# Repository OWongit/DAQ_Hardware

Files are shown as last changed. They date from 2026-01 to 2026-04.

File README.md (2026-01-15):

# High-Precision Raspberry Pi DAQ Board

A custom Data Acquisition (DAQ) hat designed for the Raspberry Pi. This board interfaces with industrial sensors (RTDs, Load Cells, Pressure Transducers) to log and display live data with high precision.

The system features a robust, low-noise power architecture that manages 24VDC input to power the sensors, the precision analog circuitry, and the Raspberry Pi itself. It utilizes dual 24-bit ADCs communicating over SPI for high-resolution signal digitization.

## Features

* **Multi-Sensor Interface:** Three 15-position D-sub connectors for attaching RTDs, Load Cells, and Pressure Transducers.
* **Input Protection:** Every signal line is protected by TVS diode arrays to guard against ESD and surge events.
* **High-Resolution Sampling:** Dual 24-bit ADCs transmit data via SPI to the Raspberry Pi.
* **Low-Noise Power Architecture:**
    * Accepts 24 VDC input.
    * On-board Buck converters for high-efficiency voltage step-down.
    * LDOs and precision voltage references ensure clean power rails for the ADCs and sensors.
    * High-current supply dedicated to the Raspberry Pi.
* **Compact Design:** PCB fits within a 10cm x 10cm footprint to minimize manufacturing costs.

### 3D Rendering
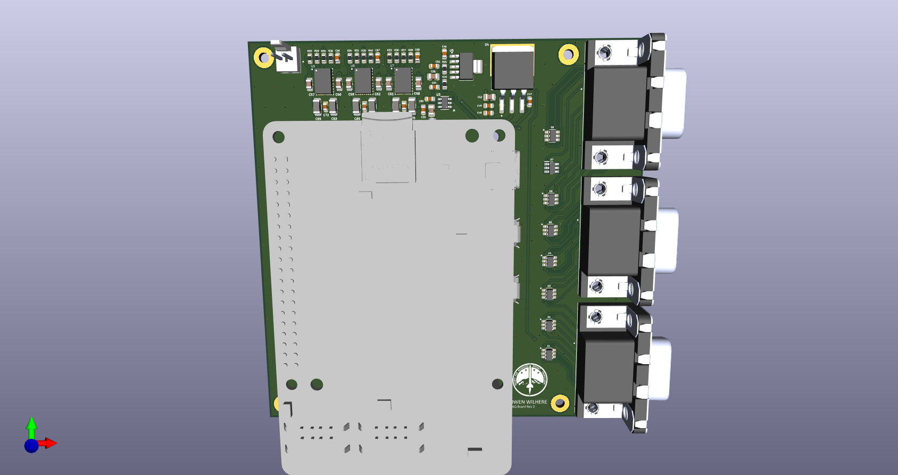
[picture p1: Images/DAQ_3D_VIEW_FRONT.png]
Business Card Front


### Layout View
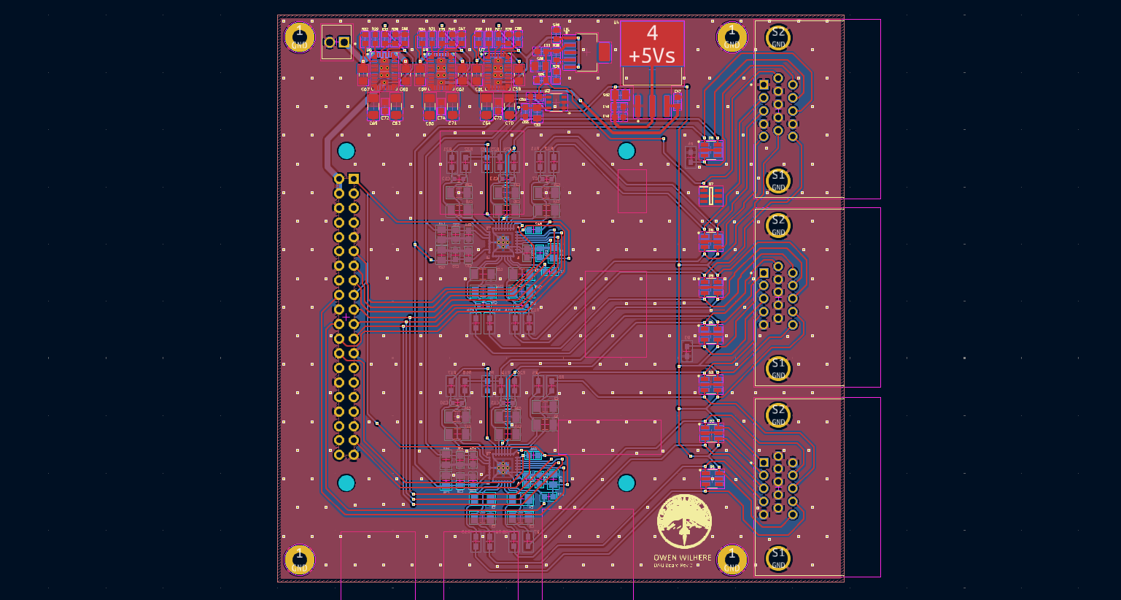
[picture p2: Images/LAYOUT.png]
PCB Layout


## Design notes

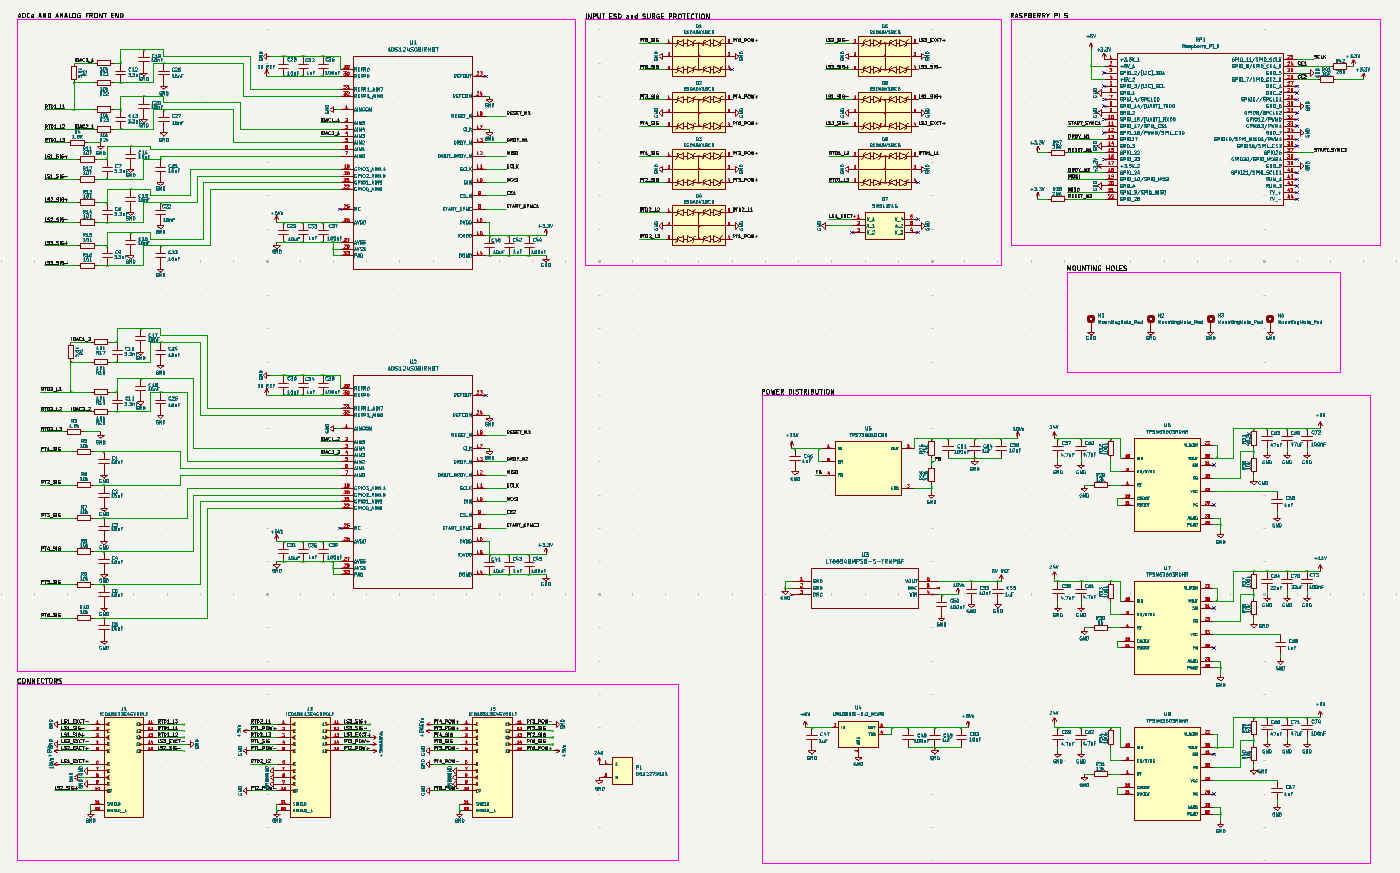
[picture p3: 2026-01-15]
Images/SCHEMATIC.png

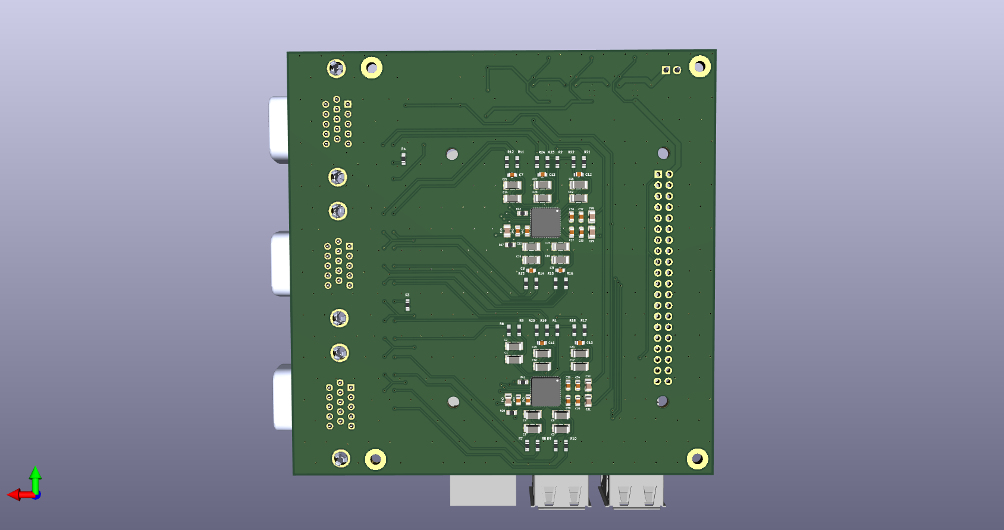
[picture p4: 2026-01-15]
Images/DAQ_3D_VIEW_BACK.png

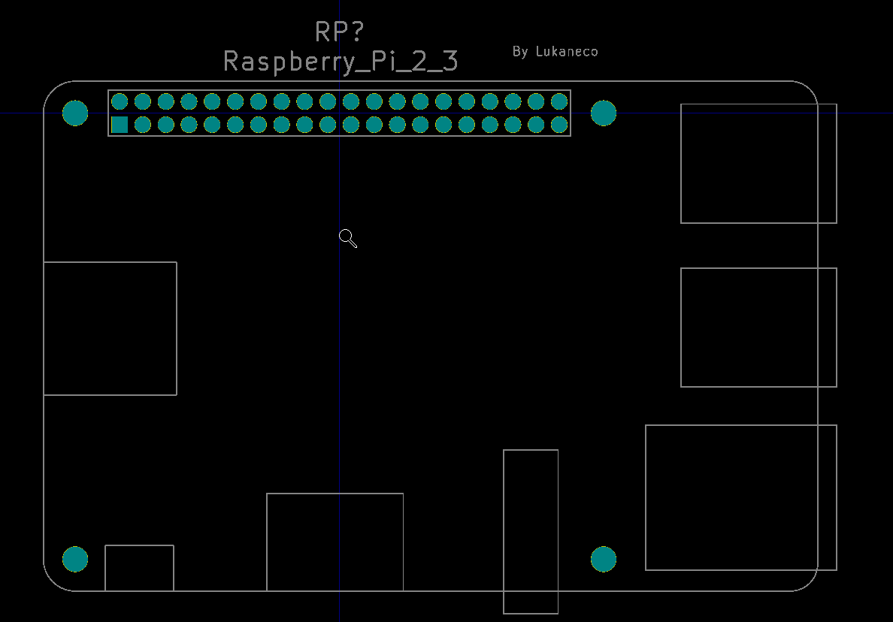
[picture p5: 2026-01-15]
DAQ symbols and footprints/raspberry pi 5/imagen.png

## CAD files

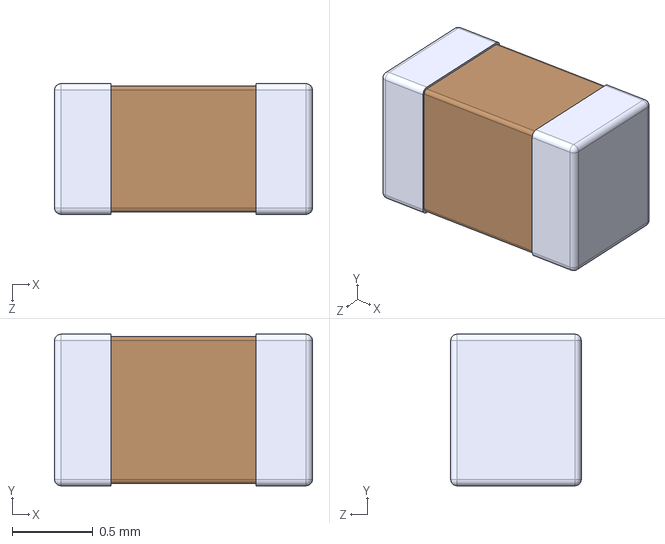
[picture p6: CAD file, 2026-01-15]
DAQ symbols and footprints/0603YC105JAT2A/CAPC1608X94N.step
1.60 x 0.94 x 0.81 mm

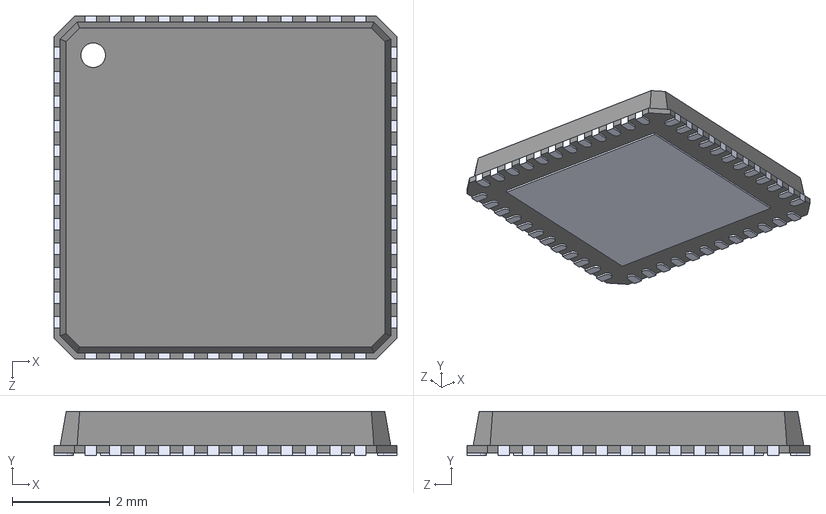
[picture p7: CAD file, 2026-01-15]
DAQ symbols and footprints/ADS1258IRTCT/ADS1258IRTCT.step
7.00 x 0.9 x 7.00 mm

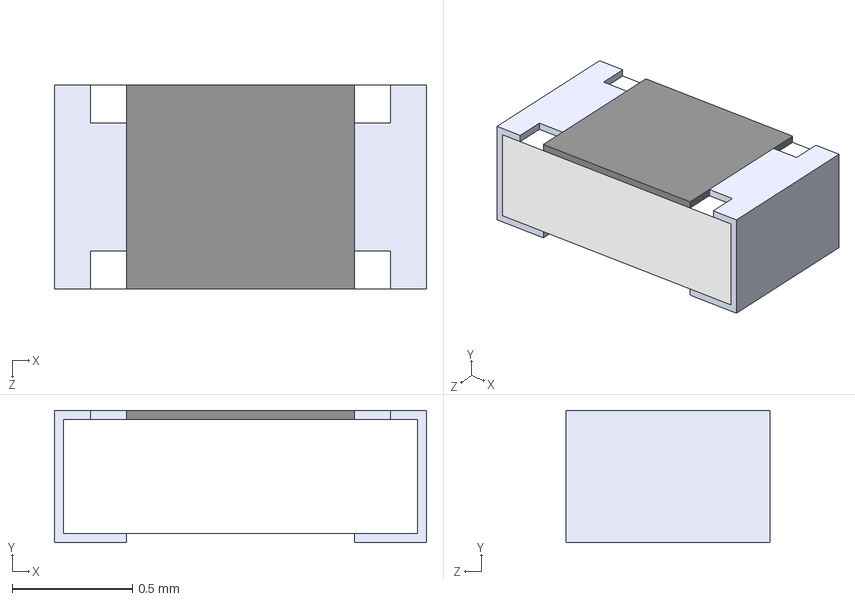
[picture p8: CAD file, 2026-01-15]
DAQ symbols and footprints/CRCW0603100KFKEA/CRCW0603100KFKEA.step
1.55 x 0.55 x 0.85 mm

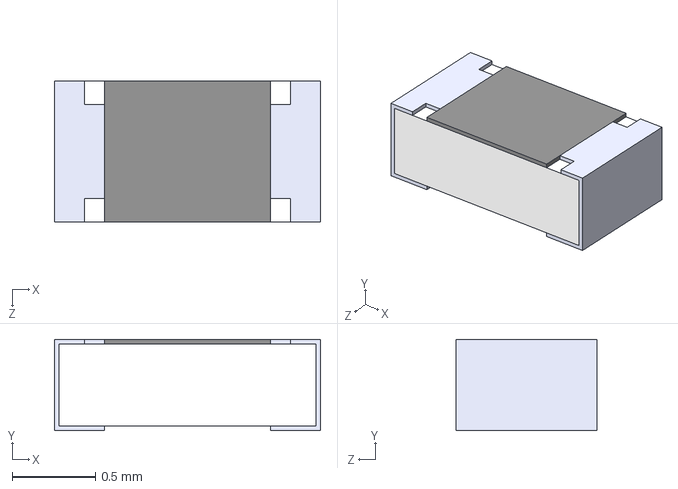
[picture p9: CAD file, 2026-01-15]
DAQ symbols and footprints/CRCW0603120RFKEAHP/CRCW0603120RFKEAHP.step
1.60 x 0.55 x 0.85 mm

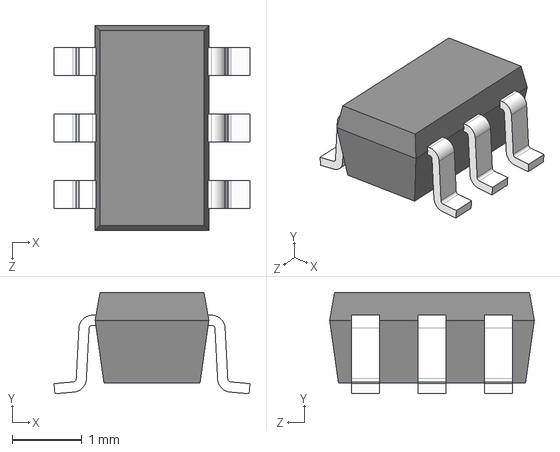
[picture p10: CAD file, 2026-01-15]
DAQ symbols and footprints/ESDA6V1BC6/ESDA6V1BC6.step
2.80 x 1.45 x 2.92 mm

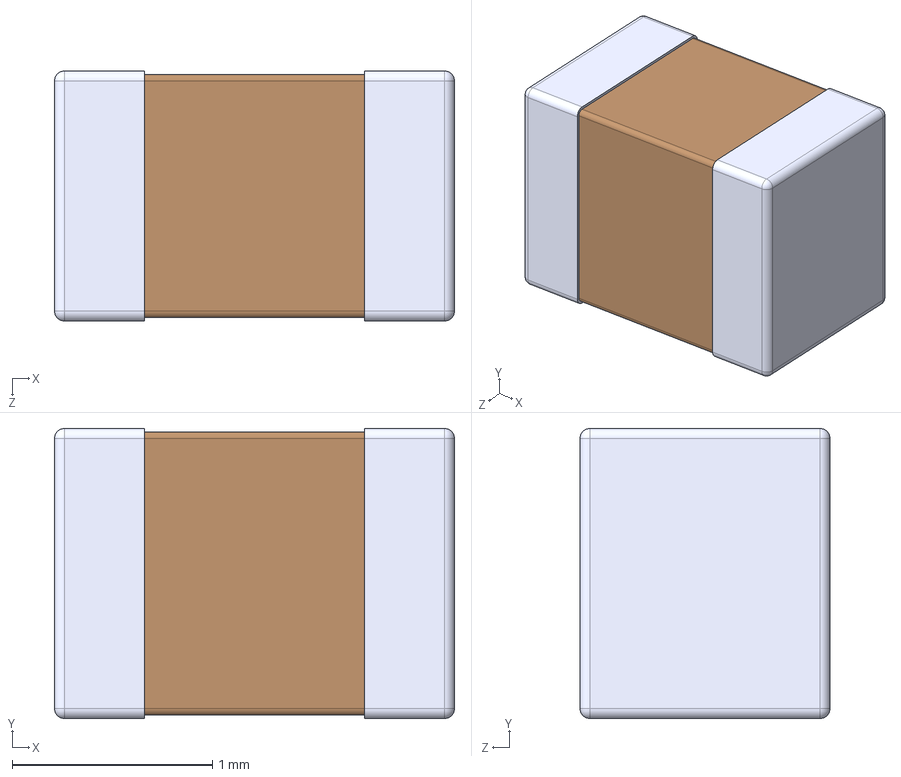
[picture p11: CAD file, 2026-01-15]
DAQ symbols and footprints/GRM21BC71E106KE11L/GRM21BC71E106KE11L.step
2.00 x 1.45 x 1.25 mm

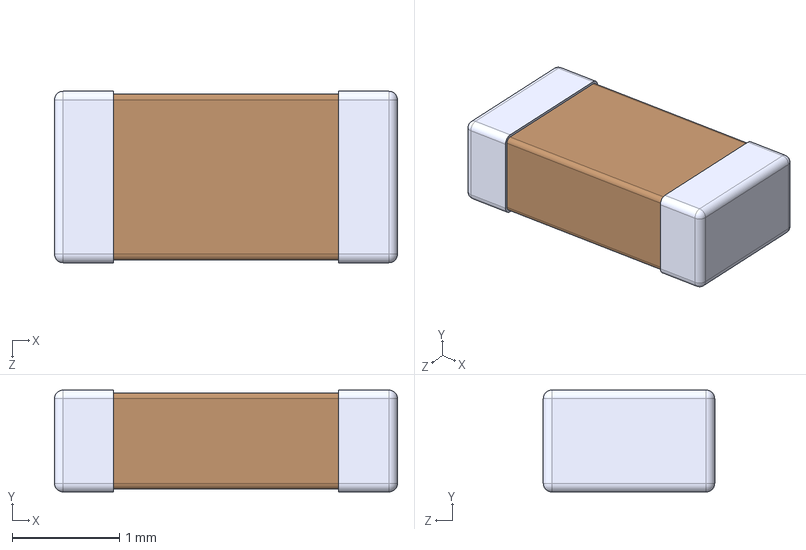
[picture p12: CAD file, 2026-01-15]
DAQ symbols and footprints/GRM3195C2A163JA01D/GRM3195C2A163JA01D.step
3.20 x 0.95 x 1.60 mm

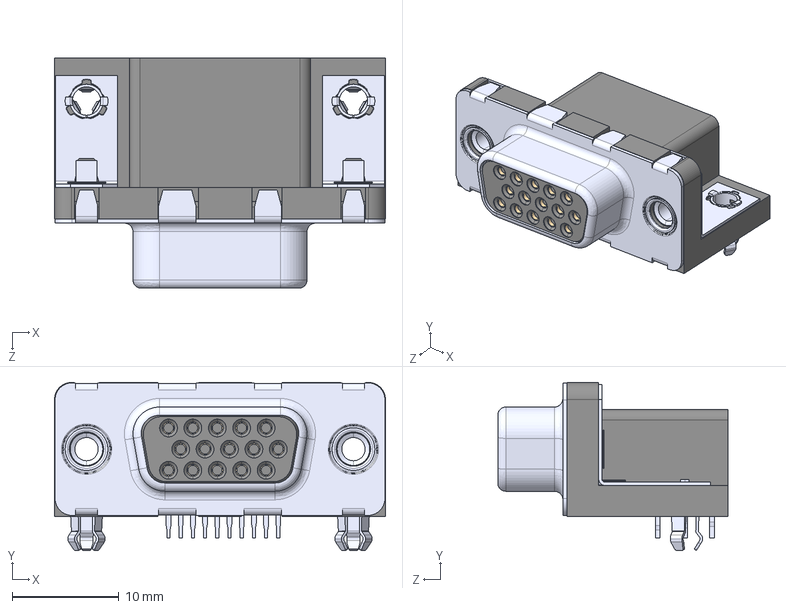
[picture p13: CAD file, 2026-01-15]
DAQ symbols and footprints/ICD15S13/ICD15S13E4GX00LF.step
31.0 x 15.7 x 21.6 mm

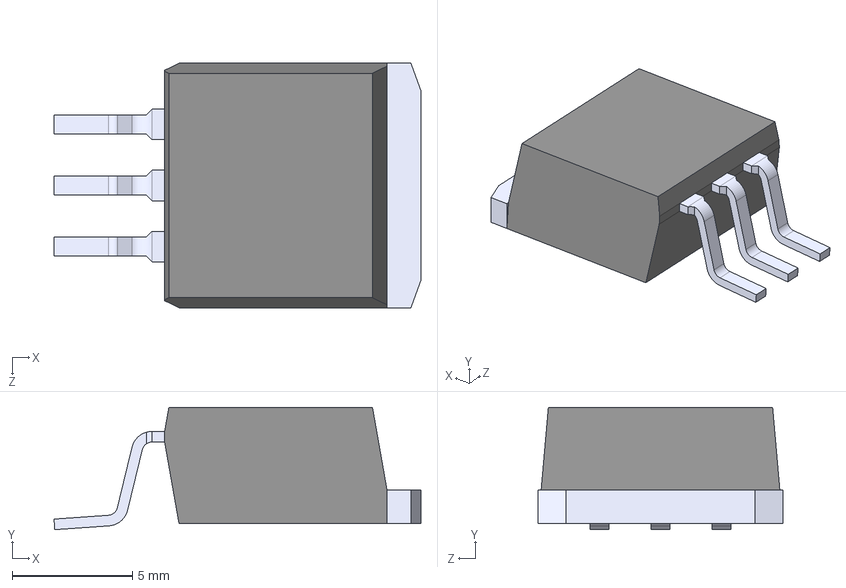
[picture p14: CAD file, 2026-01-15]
DAQ symbols and footprints/LM1086IS-5.0/LM1086IS-5.0.step
15.2 x 5.08 x 10.2 mm

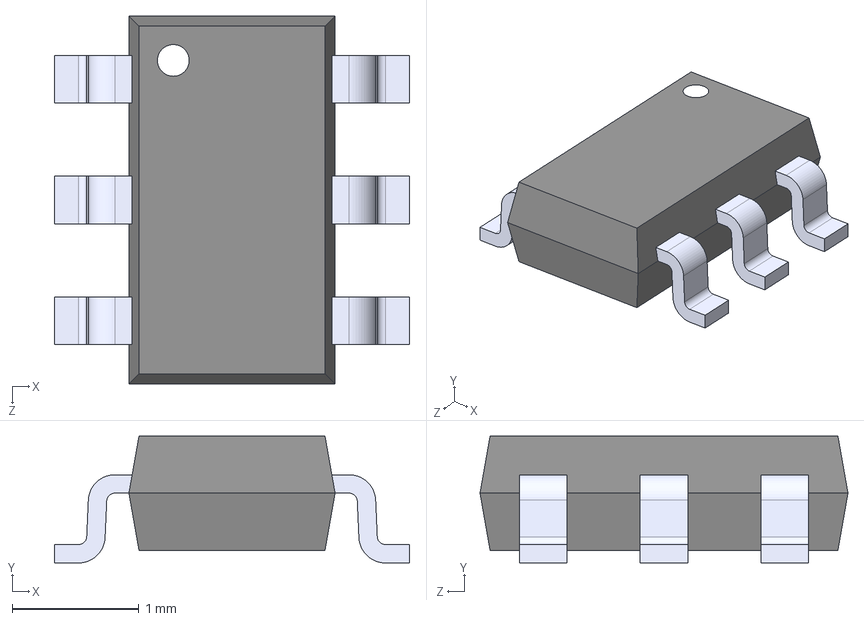
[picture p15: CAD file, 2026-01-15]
DAQ symbols and footprints/LT6654BMPS6_5_TRMPBF/LT6654BMPS6-5#TRPBF.STEP
2.80 x 1.00 x 2.90 mm

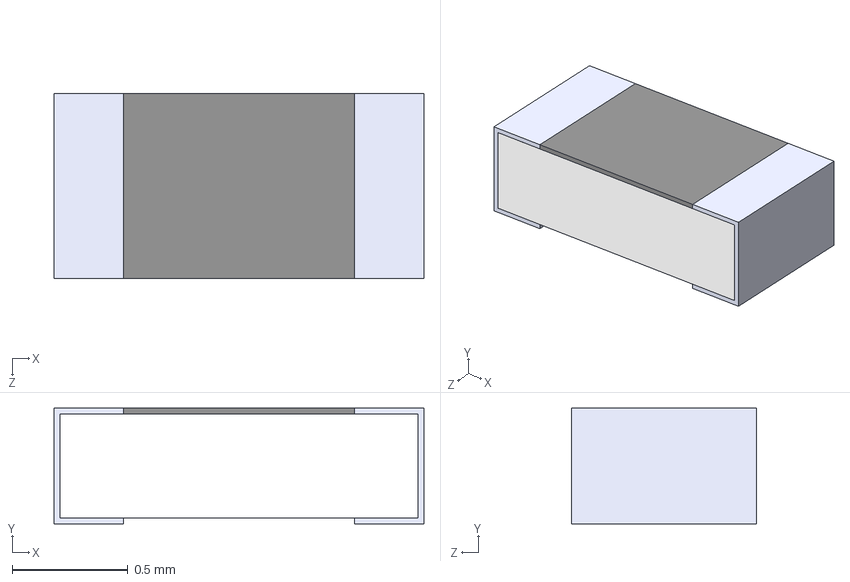
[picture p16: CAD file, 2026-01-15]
DAQ symbols and footprints/RG1608N-102-D-T5/RG1608N-102-D-T5.step
1.60 x 0.5 x 0.8 mm

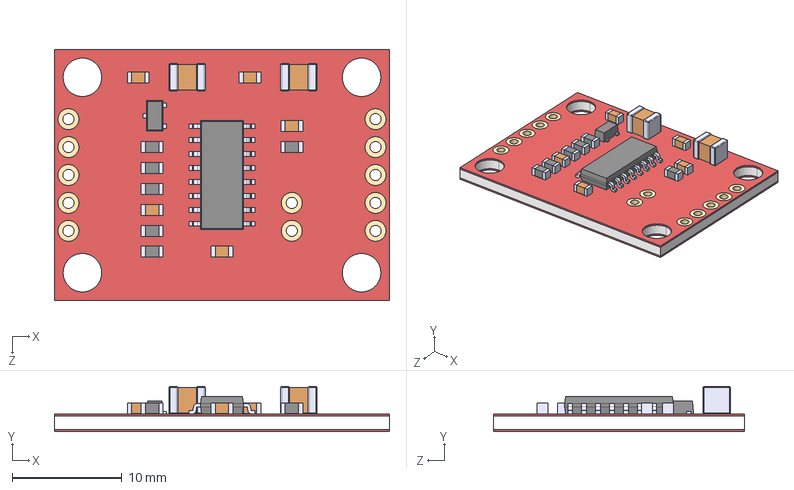
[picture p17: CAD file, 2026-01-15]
DAQ symbols and footprints/SEN-13879/SEN-13879.step
30.5 x 4.10 x 22.9 mm

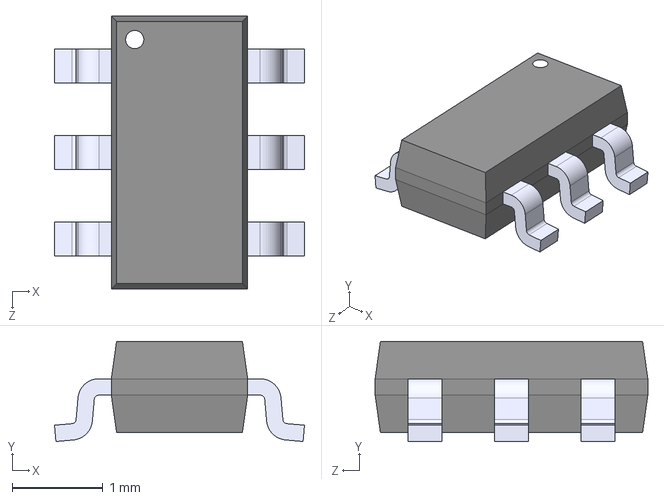
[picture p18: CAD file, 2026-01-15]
DAQ symbols and footprints/SMST12T1G/SMS12T1G.STEP
2.75 x 1.10 x 3.00 mm

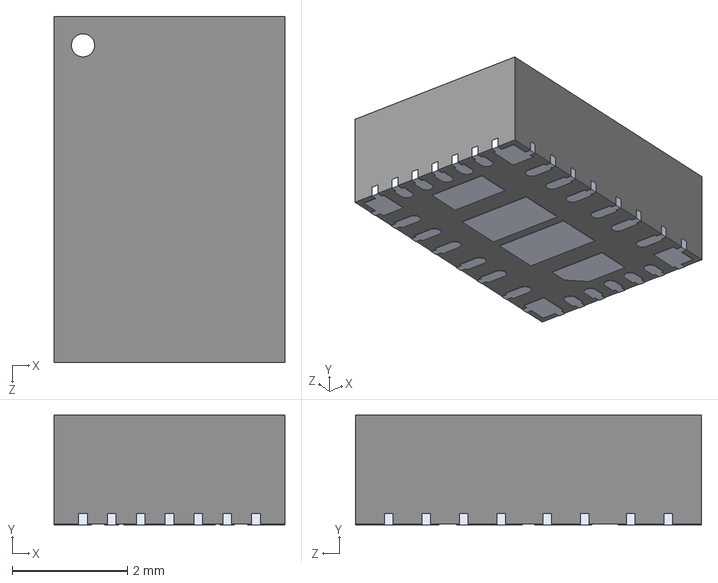
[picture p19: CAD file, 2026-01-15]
DAQ symbols and footprints/TPSM63602RDHDR/TPSM63602RDHR.step
4.00 x 1.90 x 6.00 mm

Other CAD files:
DAQ symbols and footprints/VJ0603Y104JXXAC/VJ0603Y104JXXAC.step
DAQ symbols and footprints/0022272021/0022272021.step
DAQ symbols and footprints/10090929-S154VLF/10090929-S154VLF.step
DAQ symbols and footprints/TPS73801/TPS73801DCQR.step

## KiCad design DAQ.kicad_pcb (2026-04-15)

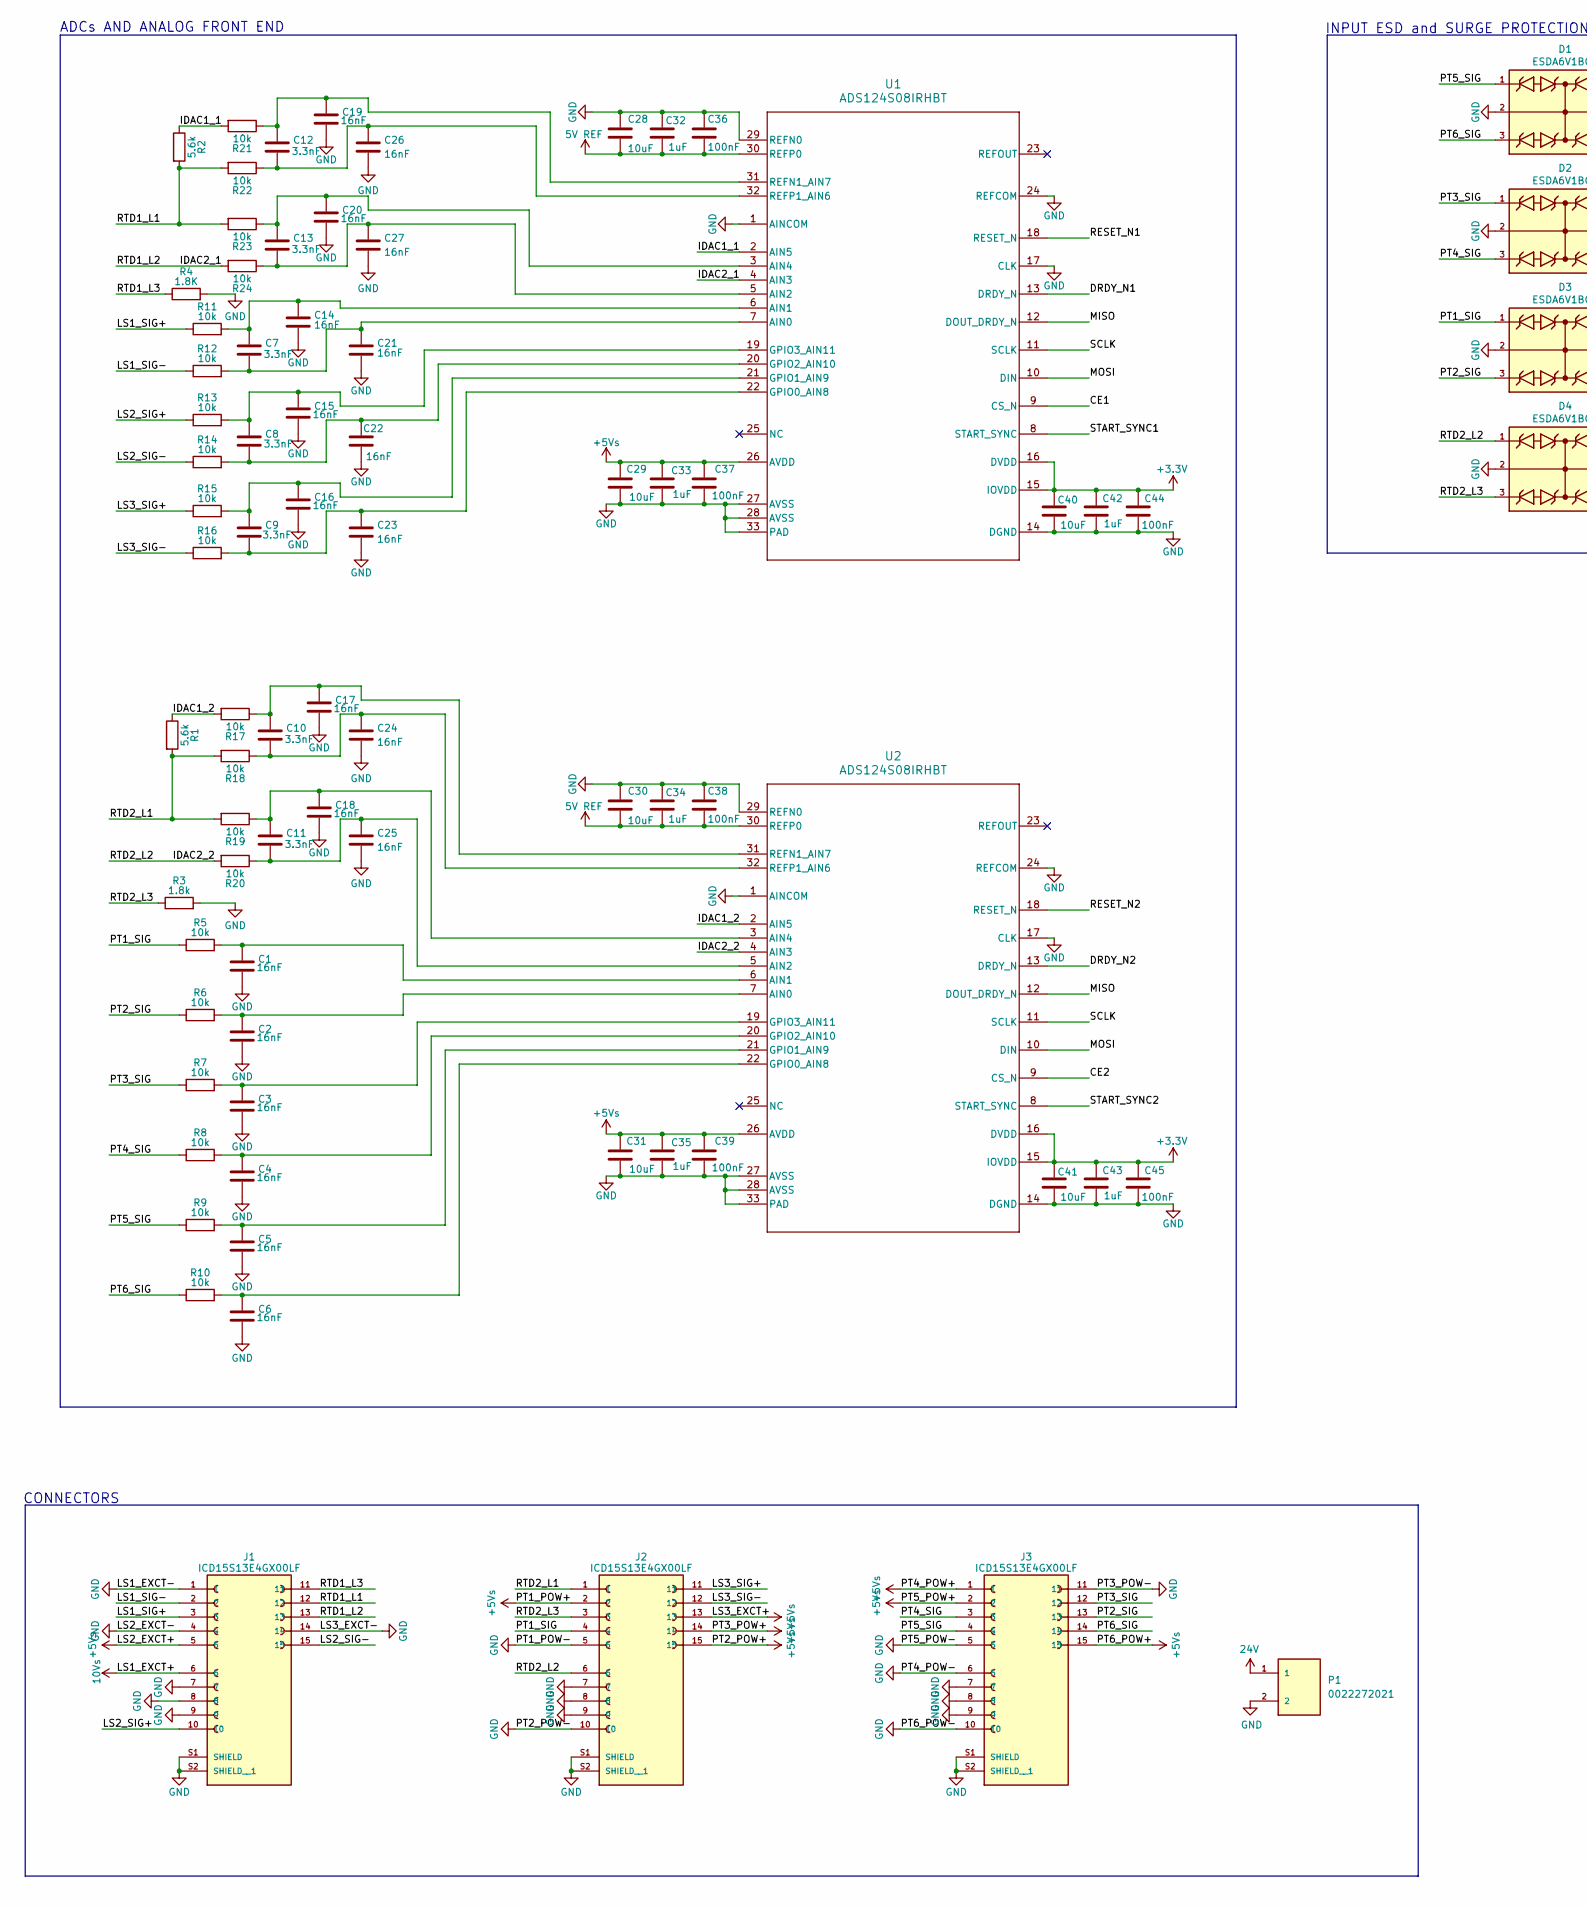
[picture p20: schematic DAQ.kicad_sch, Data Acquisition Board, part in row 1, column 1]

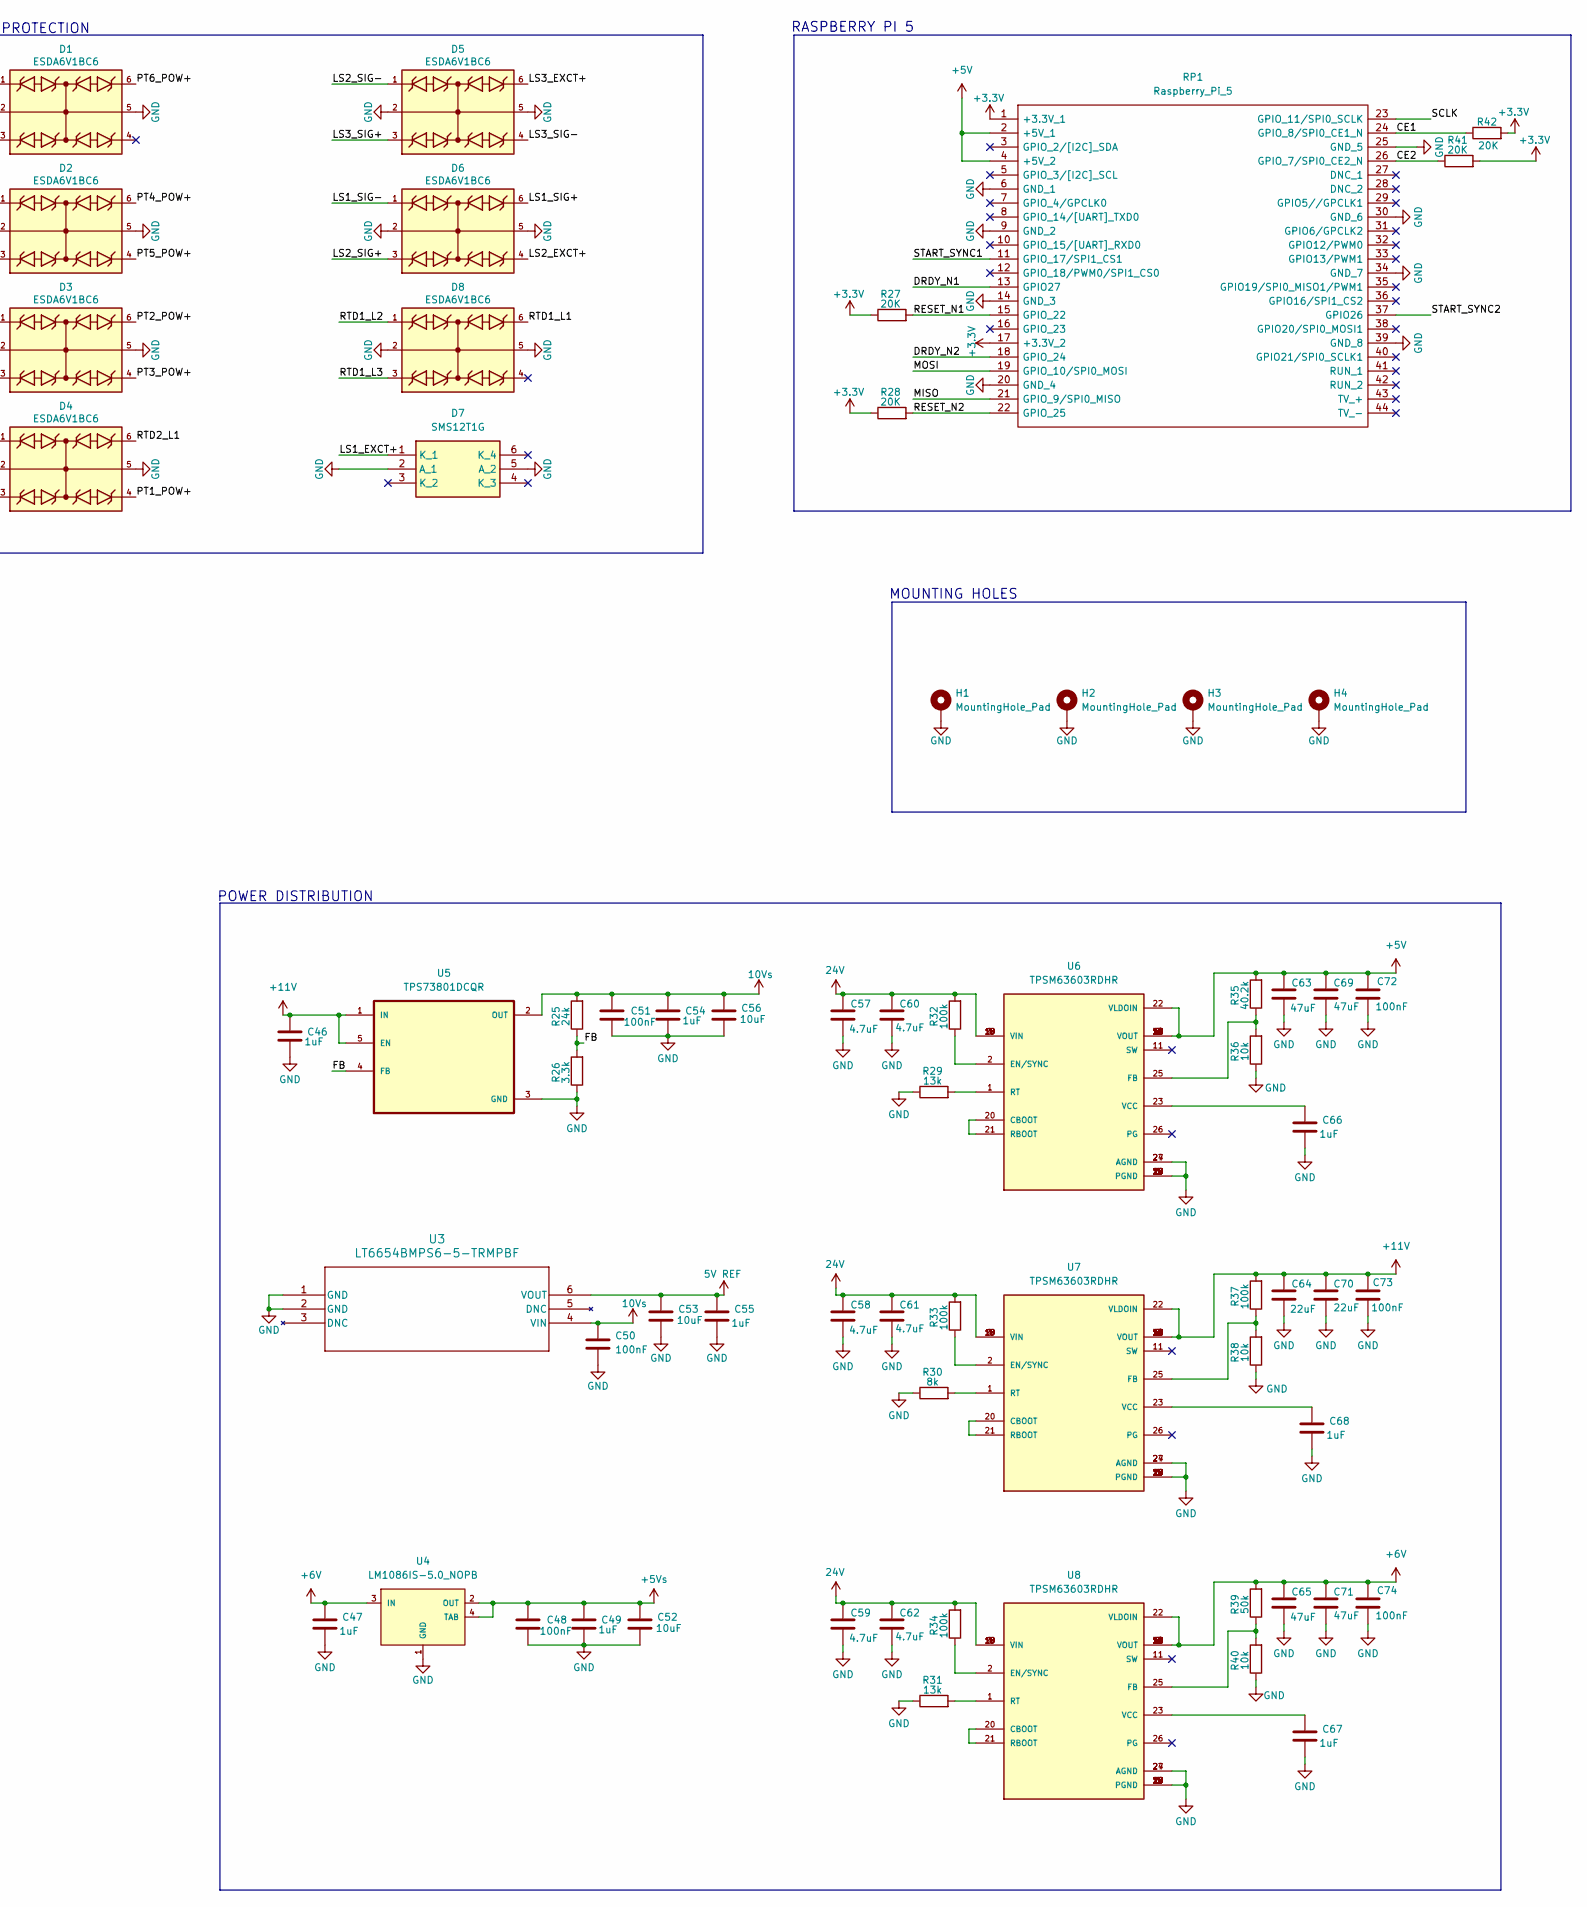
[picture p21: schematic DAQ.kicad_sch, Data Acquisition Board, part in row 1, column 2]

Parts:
C1, C2, C3, C4, C5, C6, C14, C15, C16, C17, C18, C19, C20, C21, C22, C23, C24, C25, C26, C27: 16nF; CAPC3216X95N
C7, C8, C9, C10, C11, C12, C13: 3.3nF; CAP_CL10_SAM
C28, C29, C30, C31, C40, C41, C52, C53, C56: 10uF; CAPC2012X145N
C32, C33, C34, C35, C42, C43, C46, C47, C49, C54, C55, C66, C67, C68: 1uF; CAPC1608X94N
C36, C37, C38, C39, C44, C45, C48, C50, C51, C72, C73, C74: 100nF; CAPC1608X97N
C57, C58, C59, C60, C61, C62: 4.7uF; C_0805_2012Metric_Pad1.18x1.45mm_HandSolder
C63, C65, C69, C71: 47uF; L_1206_3216Metric_Pad1.42x1.75mm_HandSolder
C64, C70: 22uF; L_1206_3216Metric_Pad1.42x1.75mm_HandSolder
D1, D2, D3, D4, D5, D6, D8: ESDA6V1BC6; SOT95P280X145-6N; PARTREV 2
D7: SMS12T1G; SOT95P275X110-6N; Manufacturer_Part_Number SMS12T1G; Mouser Part Number 863-SMS12T1G
H1, H2, H3, H4: MountingHole_Pad; MountingHole_2.5mm_Pad
J1, J2, J3: ICD15S13E4GX00LF; AMPHENOL_ICD15S13E4GX00LF; PARTREV G
P1: 0022272021; MOLEX_0022272021
R1, R2: 5.6k; RC0603N_YAG-M
R3: 1.8k; RC0603N_YAG-M
R4: 1.8K; RC0603N_YAG-M
R5, R6, R7, R8, R9, R10, R11, R12, R13, R14, R15, R16, R17, R18, R19, R20, R21, R22, R23, R24: 10k; RC0603N_YAG-M
R25: 24k; RESC1508X50N
R26: 3.3k; RESC1508X50N
R27, R28, R41, R42: 20K; RESC1508X50N
R29, R31: 13k; RESC1508X50N
R30: 8k; RESC1508X50N
R32, R33, R34, R37: 100k; RESC1508X50N
R35: 40.2k; RESC1508X50N
R36, R38, R40: 10k; RESC1508X50N
R39: 50k; RESC1508X50N
RP1: Raspberry_Pi_5; raspberrypi_2_3; Manufacturer_Part_Number Raspberry Pi 2 or 3
U1, U2: ADS124S08IRHBT; RHB0032M
U3: LT6654BMPS6-5-TRMPBF; TSOT-23_S6_LIT
U4: LM1086IS-5.0_NOPB; TO254P1524X483-4N
U5: TPS73801DCQR; SOT127P706X180-6N
U6, U7, U8: TPSM63603RDHR; CONV_TPSM63602RDHR; PARTREV April 2022

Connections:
5V REF: C28.2, C30.2, C32.2, C34.2, C36.2, C38.2, C53.1, C55.1, U1.30 (REFP0), U2.30 (REFP0), U3.6 (VOUT)
10Vs: C50.1, C51.1, C54.1, C56.1, D7.1 (K_1), J1.6, R25.2, U3.4 (VIN), U5.2 (OUT)
24V: C57.2, C58.2, C59.2, C60.2, C61.2, C62.2, P1.1, R32.2, R33.2, R34.2, U6.3 (VIN), U6.4 (VIN), U6.18 (VIN), U6.19 (VIN), U7.3 (VIN), U7.4 (VIN), U7.18 (VIN), U7.19 (VIN), U8.3 (VIN), U8.4 (VIN), U8.18 (VIN), U8.19 (VIN)
+3.3V: C40.1, C41.1, C42.1, C43.1, C44.1, C45.1, R27.1, R28.1, R41.2, R42.2, RP1.1 (+3.3V_1), RP1.17 (+3.3V_2), U1.15 (IOVDD), U1.16 (DVDD), U2.15 (IOVDD), U2.16 (DVDD)
+5V: C63.2, C69.2, C72.1, R35.2, RP1.2 (+5V_1), RP1.4 (+5V_2), U6.7 (VOUT), U6.8 (VOUT), U6.9 (VOUT), U6.10 (VOUT), U6.12 (VOUT), U6.13 (VOUT), U6.14 (VOUT), U6.15 (VOUT), U6.22 (VLDOIN), U6.30 (VOUT), U6.31
+5Vs: C29.1, C31.1, C33.1, C35.1, C37.1, C39.1, C48.1, C49.1, C52.1, D1.6, D2.4, D2.6, D3.4, D3.6, D4.4, D5.6, D6.4, J1.5, J2.2, J2.13, J2.14, J2.15, J3.1, J3.2, J3.15, U1.26 (AVDD), U2.26 (AVDD), U4.2 (OUT), U4.4 (TAB)
+6V: C47.1, C65.2, C71.2, C74.1, R39.2, U4.3 (IN), U8.7 (VOUT), U8.8 (VOUT), U8.9 (VOUT), U8.10 (VOUT), U8.12 (VOUT), U8.13 (VOUT), U8.14 (VOUT), U8.15 (VOUT), U8.22 (VLDOIN), U8.30 (VOUT), U8.31
+11V: C46.1, C64.2, C70.2, C73.1, R37.2, U5.1 (IN), U5.5 (EN), U7.7 (VOUT), U7.8 (VOUT), U7.9 (VOUT), U7.10 (VOUT), U7.12 (VOUT), U7.13 (VOUT), U7.14 (VOUT), U7.15 (VOUT), U7.22 (VLDOIN), U7.30 (VOUT), U7.31
/CE1: R42.1, RP1.24 (GPIO_8/SPI0_CE1_N), U1.9 (CS_N)
/CE2: R41.1, RP1.26 (GPIO_7/SPI0_CE2_N), U2.9 (CS_N)
/DRDY_N1: RP1.13 (GPIO27), U1.13 (DRDY_N)
/DRDY_N2: RP1.18 (GPIO_24), U2.13 (DRDY_N)
/FB: R25.1, R26.2, U5.4 (FB)
/IDAC1_1: R2.1, R21.2, U1.2 (AIN5)
/IDAC1_2: R1.1, R17.2, U2.2 (AIN5)
/IDAC2_1: D8.1, J1.13, R24.2, U1.4 (AIN3)
/IDAC2_2: D4.1, J2.6, R20.2, U2.4 (AIN3)
/LS1_SIG+: D6.6, J1.3, R11.1
/LS1_SIG-: D6.1, J1.2, R12.1
/LS2_SIG+: D6.3, J1.10, R13.1
/LS2_SIG-: D5.1, J1.15, R14.1
/LS3_SIG+: D5.3, J2.11, R15.1
/LS3_SIG-: D5.4, J2.12, R16.1
/MISO: RP1.21 (GPIO_9/SPI0_MISO), U1.12 (DOUT_DRDY_N), U2.12 (DOUT_DRDY_N)
/MOSI: RP1.19 (GPIO_10/SPI0_MOSI), U1.10 (DIN), U2.10 (DIN)
/PT1_SIG: D3.1, J2.4, R5.1
/PT2_SIG: D3.3, J3.13, R6.1
/PT3_SIG: D2.1, J3.12, R7.1
/PT4_SIG: D2.3, J3.3, R8.1
/PT5_SIG: D1.1, J3.4, R9.1
/PT6_SIG: D1.3, J3.14, R10.1
/RESET_N1: R27.2, RP1.15 (GPIO_22), U1.18 (RESET_N)
/RESET_N2: R28.2, RP1.22 (GPIO_25), U2.18 (RESET_N)
/RTD1_L1: D8.6, J1.12, R2.2, R22.2, R23.2
/RTD1_L3: D8.3, J1.11, R4.1
/RTD2_L1: D4.6, J2.1, R1.2, R18.2, R19.2
/RTD2_L3: D4.3, J2.3, R3.1
/SCLK: RP1.23 (GPIO_11/SPI0_SCLK), U1.11 (SCLK), U2.11 (SCLK)
/START_SYNC1: RP1.11 (GPIO_17/SPI1_CS1), U1.8 (START_SYNC)
/START_SYNC2: RP1.37 (GPIO26), U2.8 (START_SYNC)
GND: C1.2, C2.2, C3.2, C4.2, C5.2, C6.2, C14.2, C15.2, C16.2, C17.2, C18.2, C19.2, C20.2, C21.2, C22.2, C23.2, C24.2, C25.2, C26.2, C27.2, C28.1, C29.2, C30.1, C31.2, C32.1, C33.2, C34.1, C35.2, C36.1, C37.2, C38.1, C39.2, C40.2, C41.2, C42.2, C43.2, C44.2, C45.2, C46.2, C47.2, C48.2, C49.2, C50.2, C51.2, C52.2, C53.2, C54.2, C55.2, C56.2, C57.1, C58.1, C59.1, C60.1, C61.1, C62.1, C63.1, C64.1, C65.1, C66.2, C67.2, C68.2, C69.1, C70.1, C71.1, C72.2, C73.2, C74.2, D1.2, D1.5, D2.2, D2.5, D3.2, D3.5, D4.2, D4.5, D5.2, D5.5, D6.2, D6.5, D7.2 (A_1), D7.5 (A_2), D8.2, D8.5, H1.1, H2.1, H3.1, H4.1, J1.1, J1.4, J1.7, J1.8, J1.9, J1.14, J1.S1 (SHIELD), J1.S2 (SHIELD__1), J2.5, J2.7, J2.8, J2.9, J2.10, J2.S1 (SHIELD), J2.S2 (SHIELD__1), J3.5, J3.6, J3.7, J3.8, J3.9, J3.10, J3.11, J3.S1 (SHIELD), J3.S2 (SHIELD__1), P1.2, R3.2, R4.2, R26.1, R29.1, R30.1, R31.1, R36.1, R38.1, R40.1, RP1.6 (GND_1), RP1.9 (GND_2), RP1.14 (GND_3), RP1.20 (GND_4), RP1.25 (GND_5), RP1.30 (GND_6), RP1.34 (GND_7), RP1.39 (GND_8), U1.1 (AINCOM), U1.14 (DGND), U1.17 (CLK), U1.24 (REFCOM), U1.27 (AVSS), U1.28 (AVSS), U1.29 (REFN0), U1.33 (PAD), U1.V, U2.1 (AINCOM), U2.14 (DGND), U2.17 (CLK), U2.24 (REFCOM), U2.27 (AVSS), U2.28 (AVSS), U2.29 (REFN0), U2.33 (PAD), U2.V, U3.1 (GND), U3.2 (GND), U4.1 (GND), U5.3 (GND), U6.5 (PGND), U6.6 (PGND), U6.16 (PGND), U6.17 (PGND), U6.24 (AGND), U6.27 (AGND), U6.28 (PGND), U6.29 (PGND), U6.32, U6.33, U6.34, U6.35, U6.36, U7.5 (PGND), U7.6 (PGND), U7.16 (PGND), U7.17 (PGND), U7.24 (AGND), U7.27 (AGND), U7.28 (PGND), U7.29 (PGND), U7.32, U7.33, U7.34, U7.35, U7.36, U8.5 (PGND), U8.6 (PGND), U8.16 (PGND), U8.17 (PGND), U8.24 (AGND), U8.27 (AGND), U8.28 (PGND), U8.29 (PGND), U8.32, U8.33, U8.34, U8.35, U8.36
unnamed: C7.2, C21.1, R12.2, U1.7 (AIN0)
unnamed: C7.1, C14.1, R11.2, U1.6 (AIN1)
unnamed: C13.2, C27.1, R24.1, U1.5 (AIN2)
unnamed: C13.1, C20.1, R23.1, U1.3 (AIN4)
unnamed: C9.2, C23.1, R16.2, U1.22 (GPIO0_AIN8)
unnamed: C9.1, C16.1, R15.2, U1.21 (GPIO1_AIN9)
unnamed: C8.2, C22.1, R14.2, U1.20 (GPIO2_AIN10)
unnamed: C8.1, C15.1, R13.2, U1.19 (GPIO3_AIN11)
unnamed: C12.1, C19.1, R21.1, U1.31 (REFN1_AIN7)
unnamed: C12.2, C26.1, R22.1, U1.32 (REFP1_AIN6)
unnamed: C2.1, R6.2, U2.7 (AIN0)
unnamed: C1.1, R5.2, U2.6 (AIN1)
unnamed: C11.2, C25.1, R20.1, U2.5 (AIN2)
unnamed: C11.1, C18.1, R19.1, U2.3 (AIN4)
unnamed: C6.1, R10.2, U2.22 (GPIO0_AIN8)
unnamed: C5.1, R9.2, U2.21 (GPIO1_AIN9)
unnamed: C4.1, R8.2, U2.20 (GPIO2_AIN10)
unnamed: C3.1, R7.2, U2.19 (GPIO3_AIN11)
unnamed: C10.1, C17.1, R17.1, U2.31 (REFN1_AIN7)
unnamed: C10.2, C24.1, R18.1, U2.32 (REFP1_AIN6)
unnamed: U6.20 (CBOOT), U6.21 (RBOOT)
unnamed: R32.1, U6.2 (EN/SYNC)
unnamed: R35.1, R36.2, U6.25 (FB)
unnamed: R29.2, U6.1 (RT)
unnamed: C66.1, U6.23 (VCC)
unnamed: U7.20 (CBOOT), U7.21 (RBOOT)
unnamed: R33.1, U7.2 (EN/SYNC)
unnamed: R37.1, R38.2, U7.25 (FB)
unnamed: R30.2, U7.1 (RT)
unnamed: C68.1, U7.23 (VCC)
unnamed: U8.20 (CBOOT), U8.21 (RBOOT)
unnamed: R34.1, U8.2 (EN/SYNC)
unnamed: R39.1, R40.2, U8.25 (FB)
unnamed: R31.2, U8.1 (RT)
unnamed: C67.1, U8.23 (VCC)

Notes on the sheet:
RASPBERRY PI 5
MOUNTING HOLES
INPUT ESD and SURGE PROTECTION
POWER DISTRIBUTION
ADCs AND ANALOG FRONT END
CONNECTORS

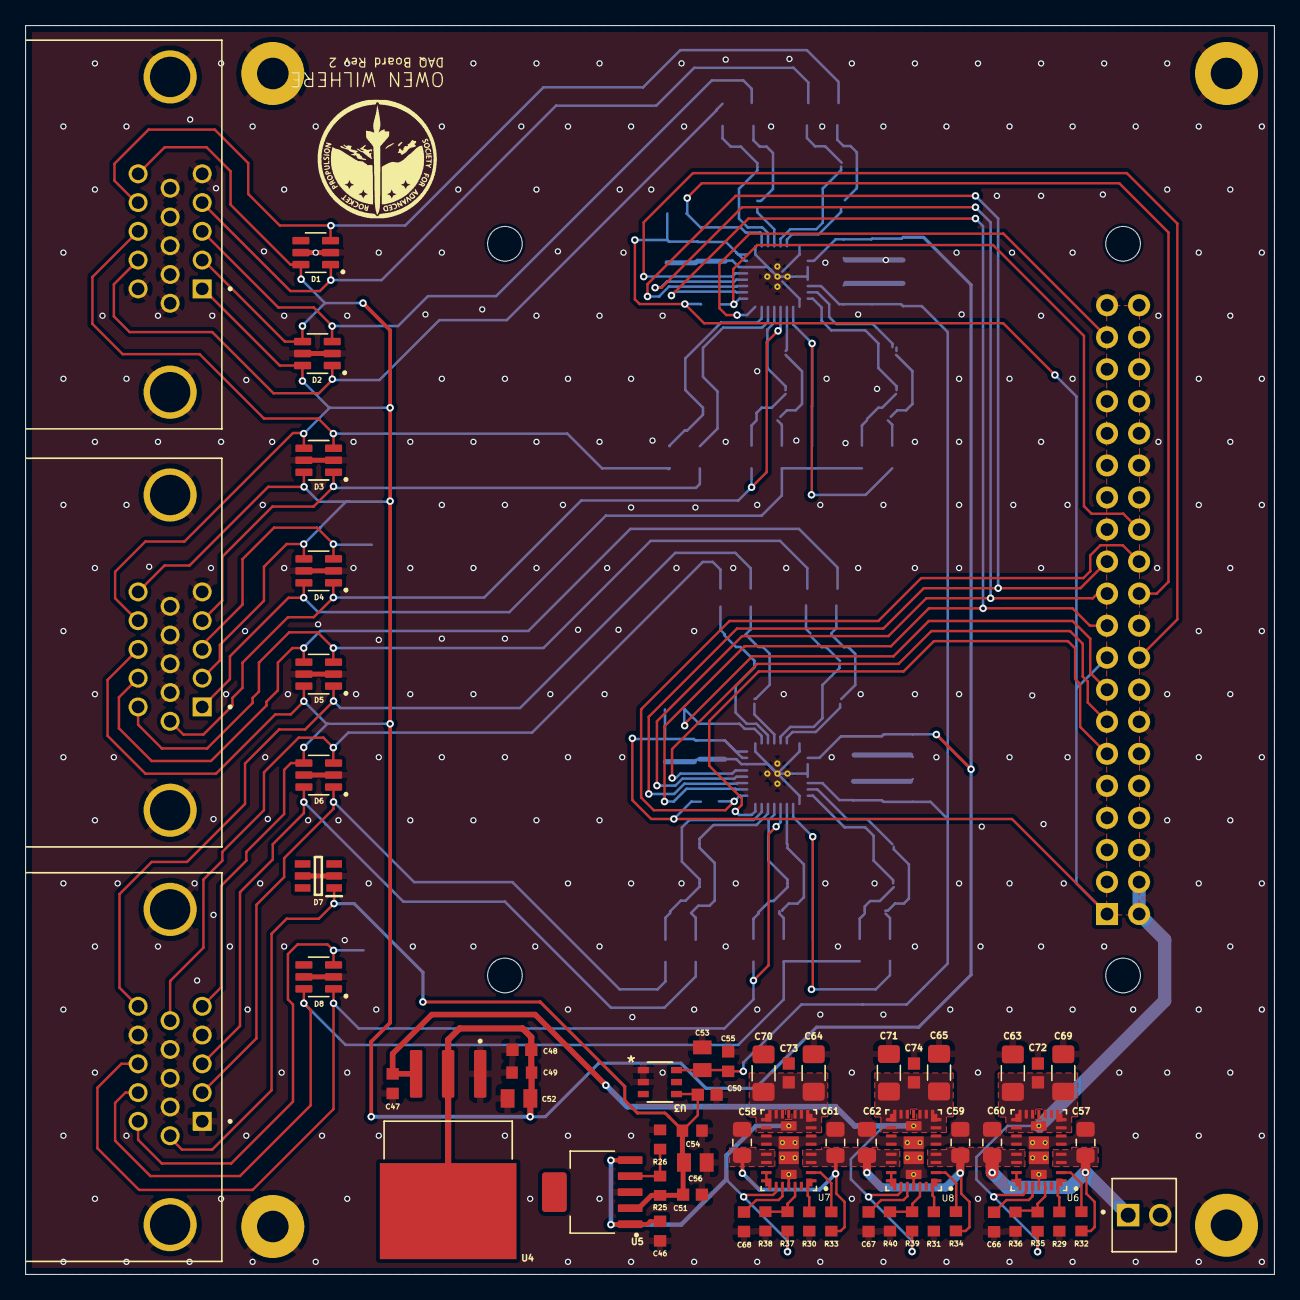
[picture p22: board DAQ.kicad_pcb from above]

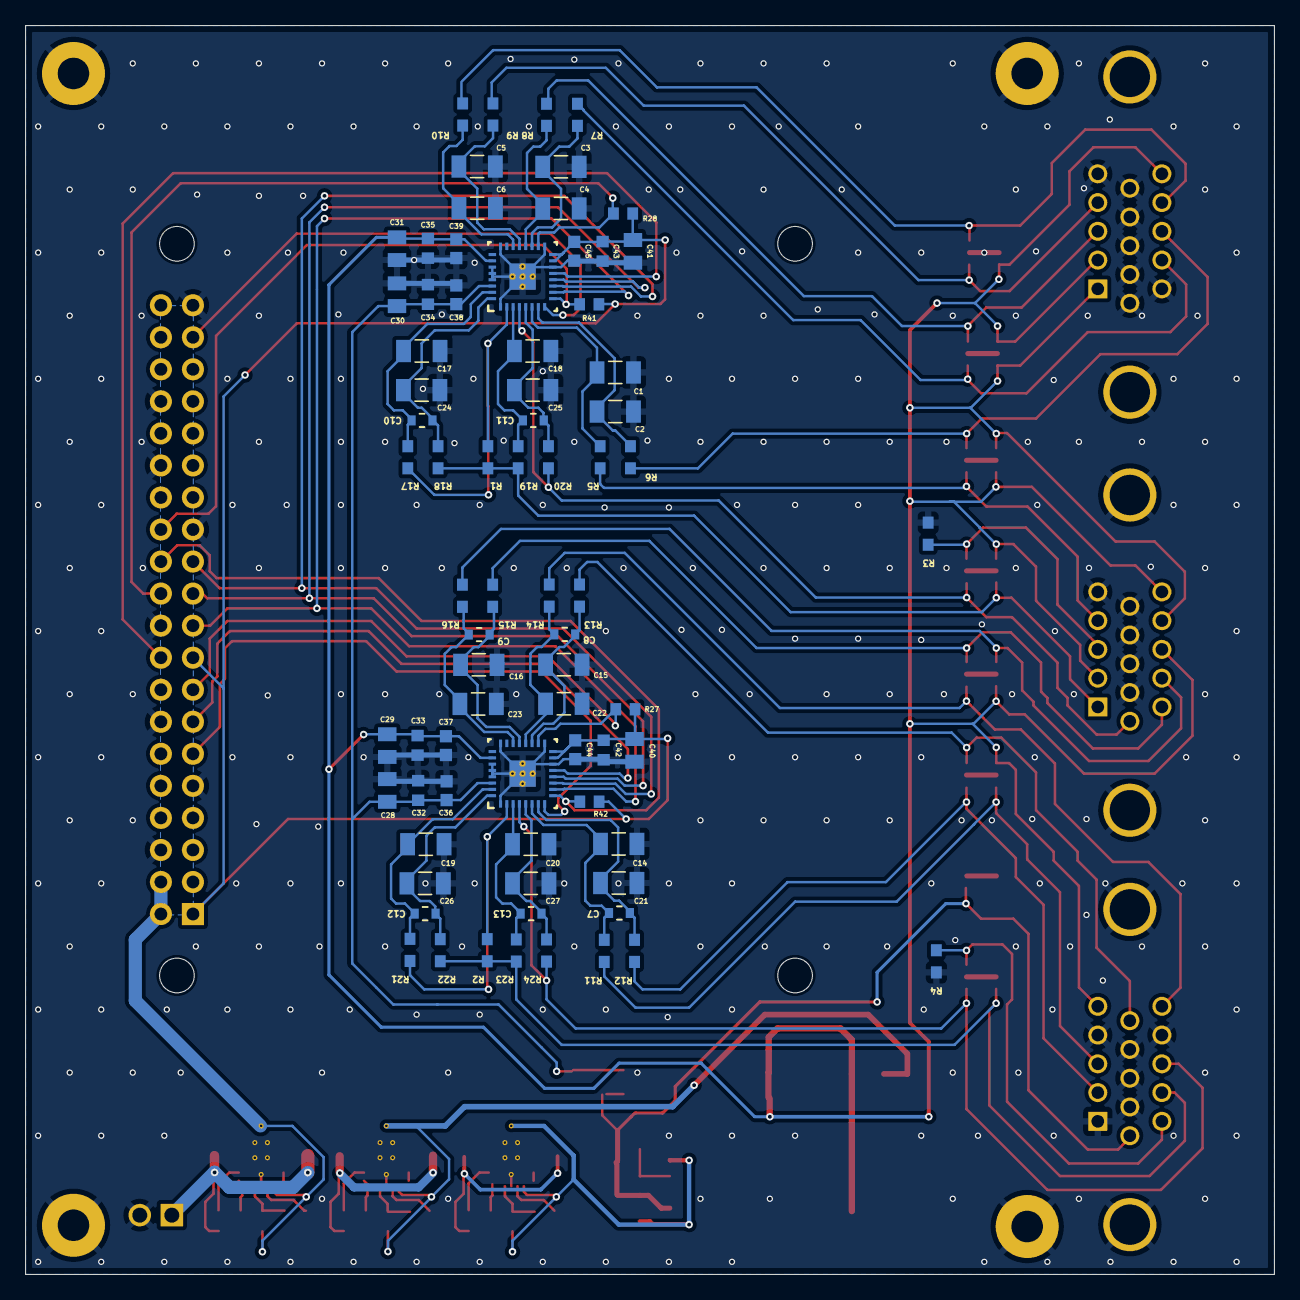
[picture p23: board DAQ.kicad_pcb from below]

Board: 2 copper layers, 99.0 x 99.0 mm, 141 parts (76 on the bottom side), 76 nets.
